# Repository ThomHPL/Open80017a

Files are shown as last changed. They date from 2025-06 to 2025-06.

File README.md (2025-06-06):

# Open80017a: an Open Source 80017a Roland Clone
<table>
  <tr>
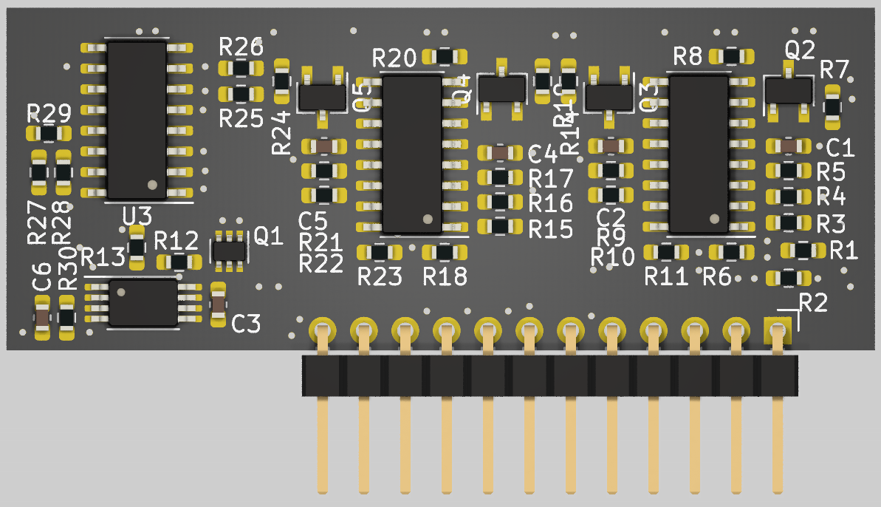
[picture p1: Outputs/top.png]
    <td align="center"><b>Top View</b><br></td>
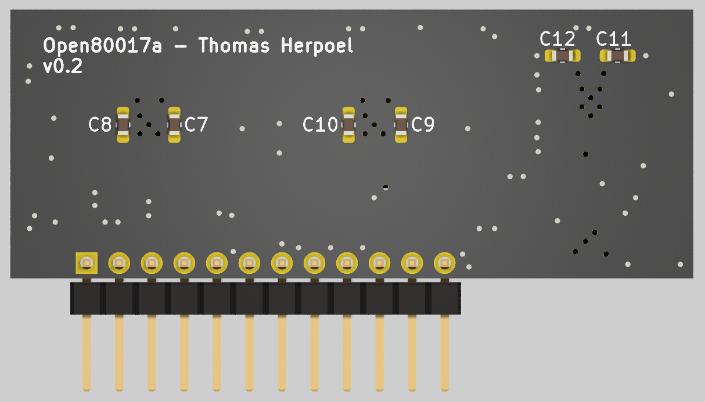
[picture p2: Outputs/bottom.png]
    <td align="center"><b>Bottom View</b><br></td>
  </tr>
</table>

## Context
The 80017a is a VCF/VCA module encapsulated in resin, used in the voices of various vintage Roland synthesizers such as the Juno-106. These modules are known to fail over time, potentially due to the resin coating.

## Open Source Aftermarket Replacement
While some clone modules are available for sale, they are often hard to find or relatively expensive. To be 100% honest, this project is also mostly a learning opportunity for me in vintage analog synth design.

### Key Design Focus Points
- **EMC Best Practices**
    - 4-layer PCB design
    - Proper trace spacing
- **Thermal Stability**
    - Vias under the OTAs to (try to) thermally couple them using an internal ground plane
- **Miniaturization**
    - Tries to match the original module dimensions

### Schematic

[](Outputs/Open80017a.pdf)

### Production
While the project uses a 4-layer board design, it has not requirements considering impedance control. It can therefore be made with any cheap 4-layer online service.

## Tests
Version 0.1 was assembled and tested in a Juno-106, with no perceivable difference (to my ears) between the clone and the original voices. However, there was an error in the buffer PMOS footprint, which was corrected with bodge wires.

Version 0.2 fixes the footprints. It has not yet been assembled or tested.

## Support

If you like my work, you can contribute with a coffee there ;)



## Credits
- This work was motivated by a dead channel on my brother's Juno-106. Thanks for the opportunity to help bro'!
- It would not have been possible without resources found online, especially the information provided by **dksynth** and **guest** on the following forum. Many thanks to them! [https://modwiggler.com/forum/viewtopic.php?t=238335](https://modwiggler.com/forum/viewtopic.php?t=238335)
- Thanks to [**deanm1278**](https://github.com/deanm1278) for the [LM13700 spice model](https://github.com/deanm1278/LM13700-spice-model).
- A lot of good info there as well: [80017A VCF/VCA Teardown](https://obsoletetechnology.wordpress.com/projects/80017a-vcfvca-teardown/)

## Disclaimer

While I did my best to provide a good quality design and I performed a simple test of the design, this project is provided as-is, without any warranty or guarantee. I am not responsible for any damage, malfunction, or harm caused to your hardware, equipment, or any other property resulting from the use, assembly, or modification of this project. Use at your own risk.

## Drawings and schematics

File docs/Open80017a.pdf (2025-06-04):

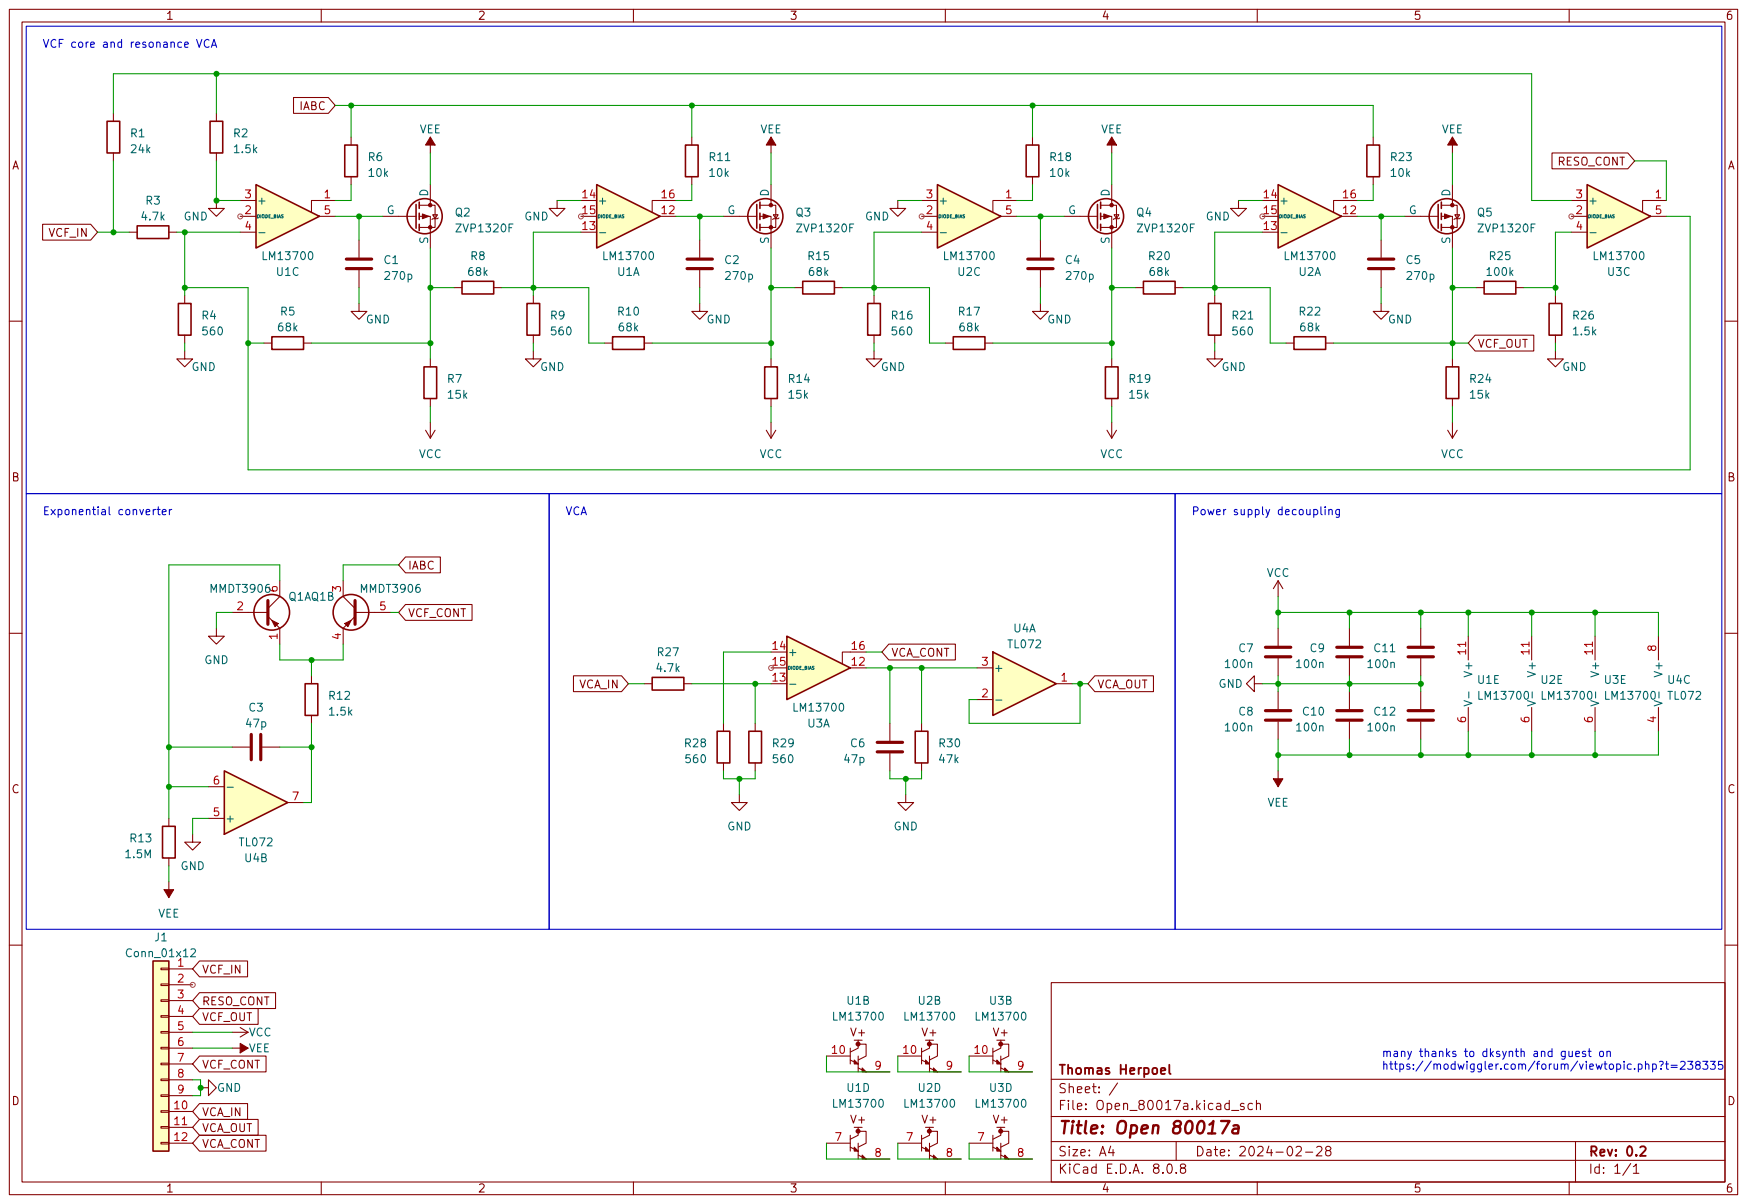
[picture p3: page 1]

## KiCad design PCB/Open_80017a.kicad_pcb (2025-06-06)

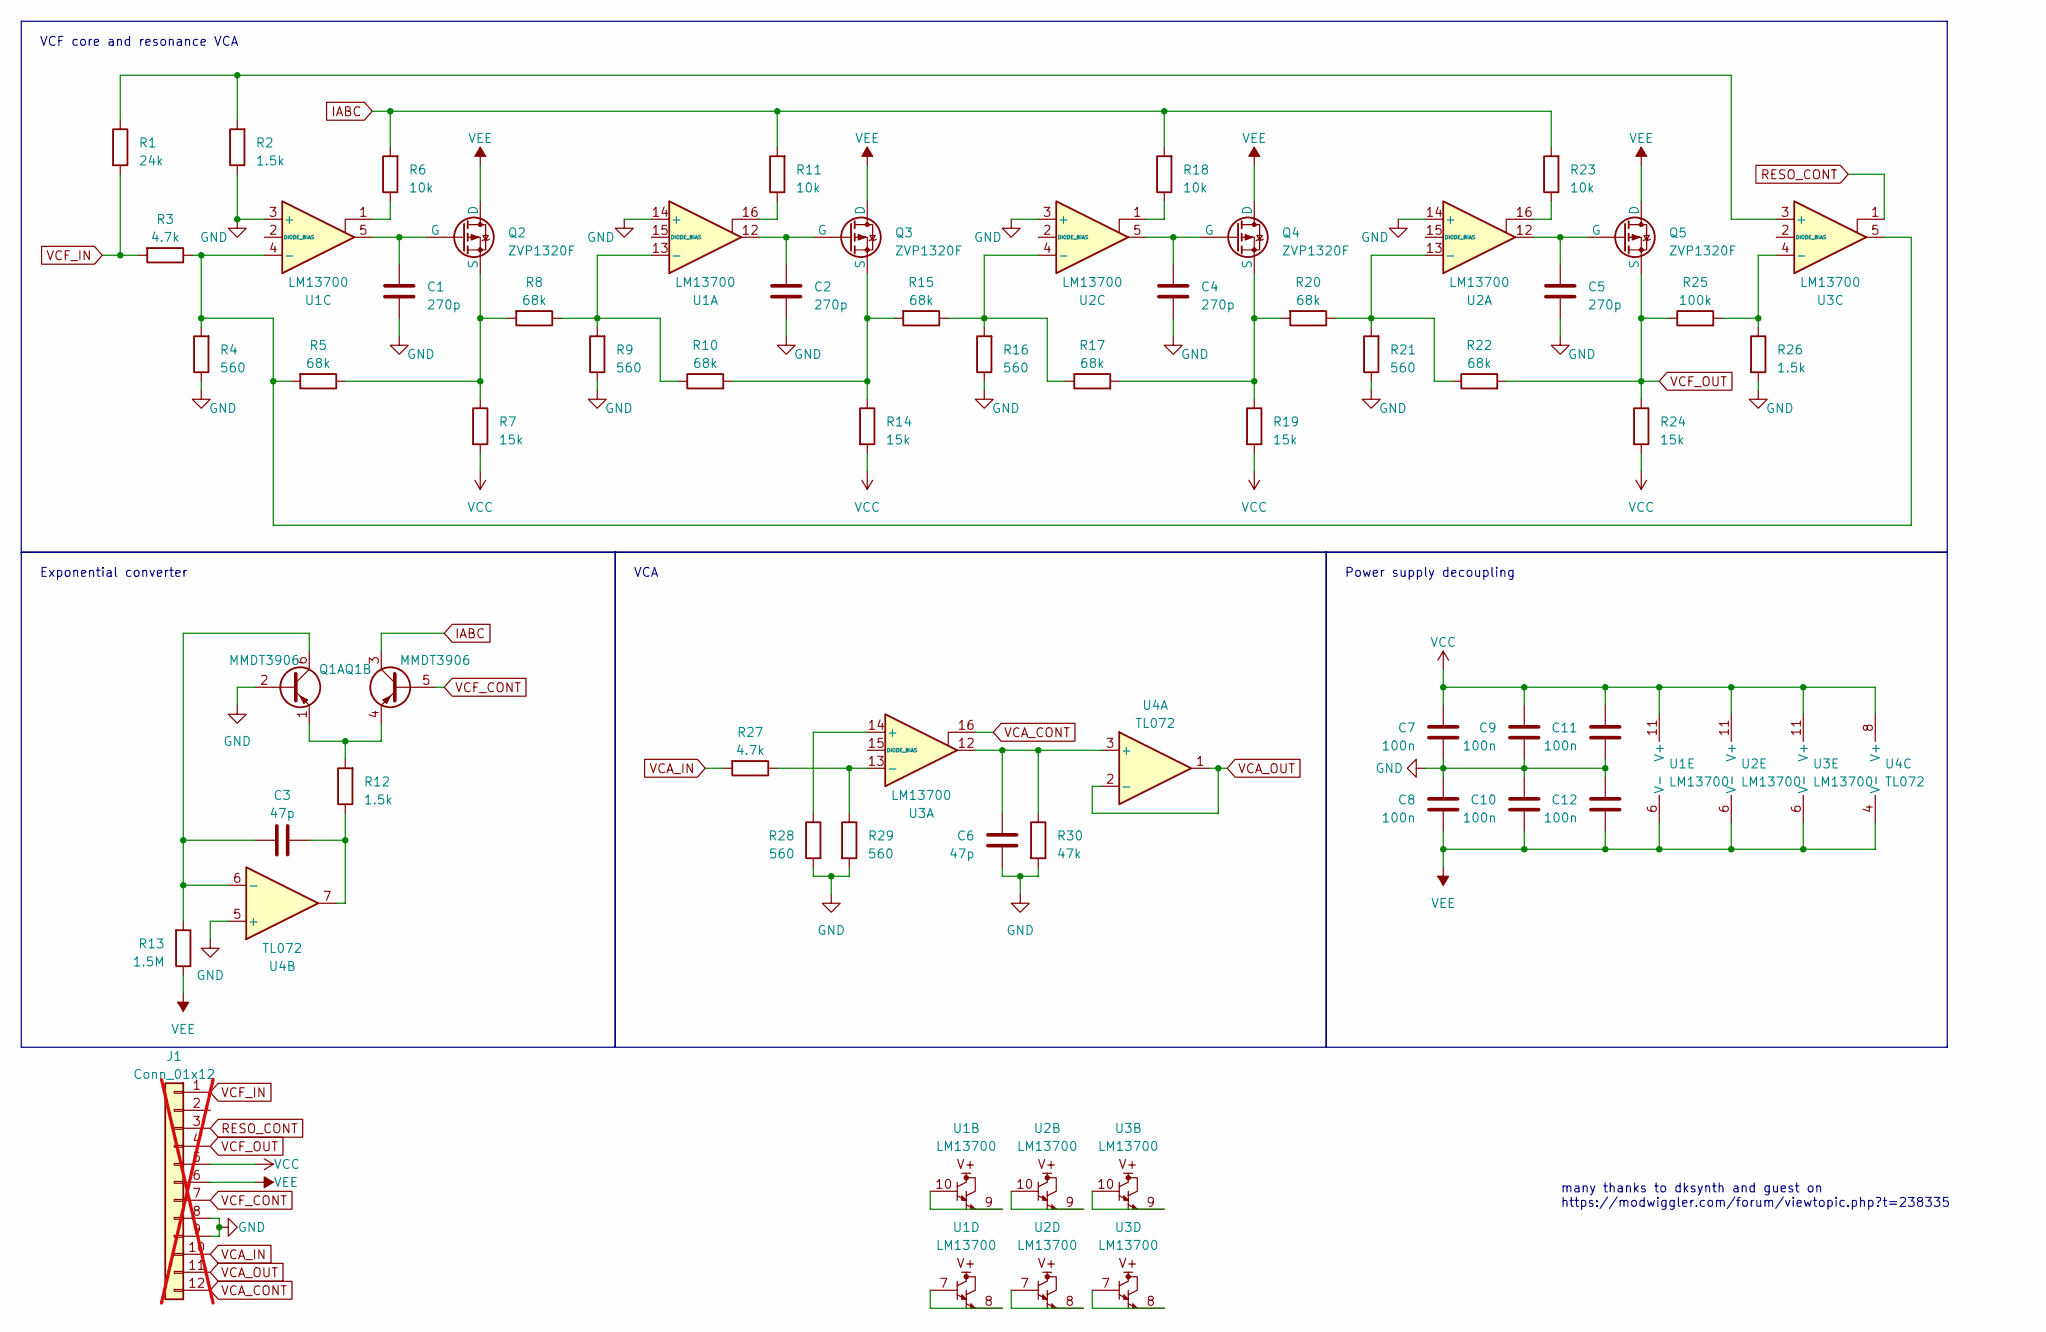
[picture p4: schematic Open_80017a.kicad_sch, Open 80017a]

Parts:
C1, C2, C4, C5: 270p; C_0603_1608Metric_Pad1.08x0.95mm_HandSolder
C3, C6: 47p; C_0603_1608Metric_Pad1.08x0.95mm_HandSolder
C7, C8, C9, C10, C11, C12: 100n; C_0603_1608Metric_Pad1.08x0.95mm_HandSolder
J1: Conn_01x12; PinHeader_1x12_P2.54mm_Horizontal; not fitted
Q1: MMDT3906; SOT-363_SC-70-6
Q2, Q3, Q4, Q5: ZVP1320F; TSOT-23
R1: 24k; R_0603_1608Metric_Pad0.98x0.95mm_HandSolder
R2, R12, R26: 1.5k; R_0603_1608Metric_Pad0.98x0.95mm_HandSolder
R3, R27: 4.7k; R_0603_1608Metric_Pad0.98x0.95mm_HandSolder
R4, R9, R16, R21, R28, R29: 560; R_0603_1608Metric_Pad0.98x0.95mm_HandSolder
R5, R8, R10, R15, R17, R20, R22: 68k; R_0603_1608Metric_Pad0.98x0.95mm_HandSolder
R6, R11, R18, R23: 10k; R_0603_1608Metric_Pad0.98x0.95mm_HandSolder
R7, R14, R19, R24: 15k; R_0603_1608Metric_Pad0.98x0.95mm_HandSolder
R13: 1.5M; R_0603_1608Metric_Pad0.98x0.95mm_HandSolder
R25: 100k; R_0603_1608Metric_Pad0.98x0.95mm_HandSolder
R30: 47k; R_0603_1608Metric_Pad0.98x0.95mm_HandSolder
U1, U2, U3: LM13700; SOIC-16_3.9x9.9mm_P1.27mm; mouser 926-LM13700M/NOPB
U4: TL072; TSSOP-8_4.4x3mm_P0.65mm

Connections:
GND: C1.2, C2.1, C4.1, C5.1, C6.1, C7.1, C8.2, C9.1, C10.2, C11.1, C12.2, J1.8, J1.9, Q1.2 (B1), R2.1, R4.1, R9.1, R16.1, R21.1, R26.2, R28.2, R29.2, R30.2, U1.3 (+), U1.14 (+), U2.3 (+), U2.14 (+), U4.5 (+)
IABC: Q1.3 (C2), R6.2, R11.2, R18.2, R23.2
unnamed: C3.2, R12.1, U4.7
unnamed: C3.1, Q1.6 (C1), R13.2, U4.6 (-)
unnamed: Q1.1 (E1), Q1.4 (E2), R12.2
unnamed: C1.1, Q2.2 (G), U1.5
unnamed: Q2.3 (S), R5.1, R7.1, R8.2
unnamed: C2.2, Q3.2 (G), U1.12
unnamed: Q3.3 (S), R10.2, R14.1, R15.2
unnamed: C4.2, Q4.2 (G), U2.5
unnamed: Q4.3 (S), R17.2, R19.1, R20.2
unnamed: C5.2, Q5.2 (G), U2.12
unnamed: R6.1, U1.1
unnamed: R11.1, U1.16
unnamed: R18.1, U2.1
unnamed: R23.1, U2.16
unnamed: U1.7, U1.8
unnamed: U1.9, U1.10
unnamed: R8.1, R9.2, R10.1, U1.13 (-)
unnamed: R3.1, R4.2, R5.2, U1.4 (-), U3.5
unnamed: U2.7, U2.8
unnamed: U2.9, U2.10
unnamed: R20.1, R21.2, R22.1, U2.13 (-)
unnamed: R15.1, R16.2, R17.1, U2.4 (-)
unnamed: U3.7, U3.8
unnamed: U3.9, U3.10
unnamed: R28.1, U3.14 (+)
unnamed: R27.1, R29.1, U3.13 (-)
unnamed: R1.1, R2.2, U3.3 (+)
unnamed: R25.2, R26.1, U3.4 (-)
unnamed: C6.2, R30.1, U3.12, U4.3 (+)
RESO_CONT: J1.3, U3.1
VCA_CONT: J1.12, U3.16
VCA_IN: J1.10, R27.2
VCA_OUT: J1.11, U4.1, U4.2 (-)
VCC: C7.2, C9.2, C11.2, J1.5, R7.2, R14.2, R19.2, R24.2, U1.11 (V+), U2.11 (V+), U3.11 (V+), U4.8 (V+)
VCF_CONT: J1.7, Q1.5 (B2)
VCF_IN: J1.1, R1.2, R3.2
VCF_OUT: J1.4, Q5.3 (S), R22.2, R24.1, R25.1
VEE: C8.1, C10.1, C12.1, J1.6, Q2.1 (D), Q3.1 (D), Q4.1 (D), Q5.1 (D), R13.1, U1.6 (V-), U2.6 (V-), U3.6 (V-), U4.4 (V-)

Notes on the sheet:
VCA
Power supply decoupling
Exponential converter
many thanks to dksynth and guest on https://modwiggler.com/forum/viewtopic.php?t=238335
VCF core and resonance VCA

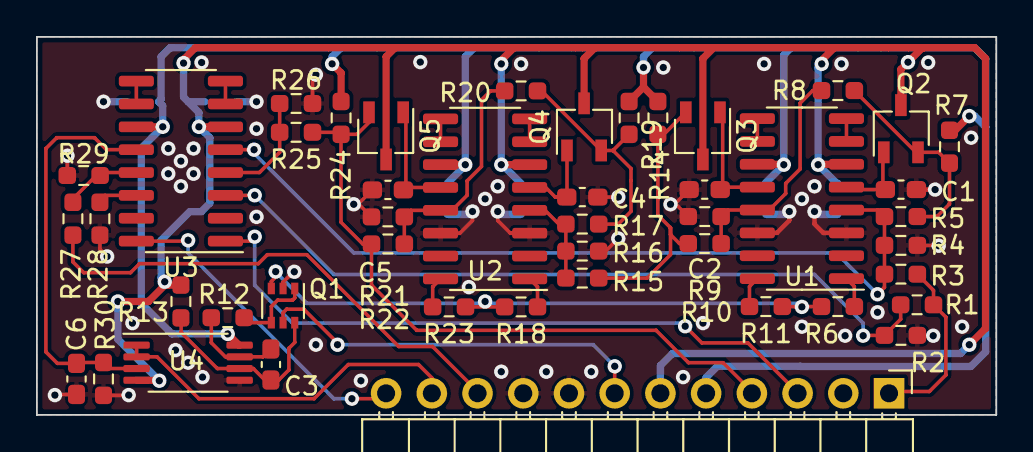
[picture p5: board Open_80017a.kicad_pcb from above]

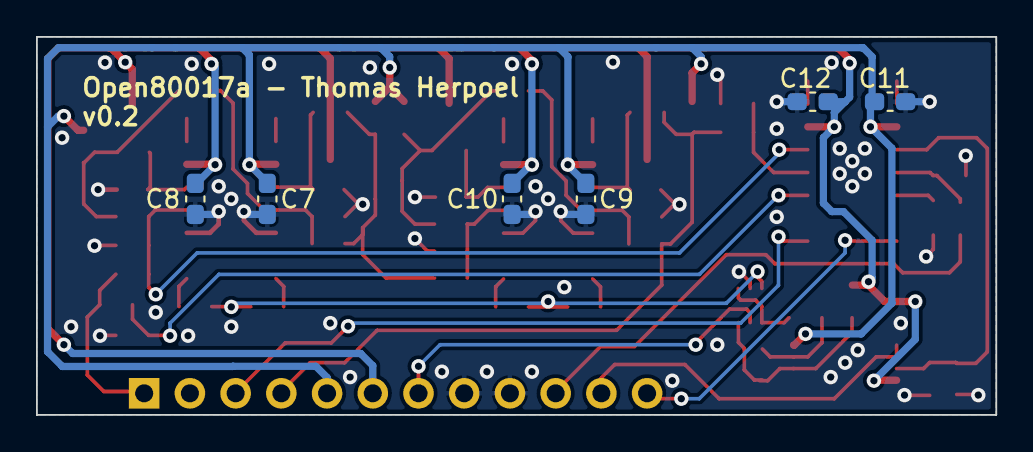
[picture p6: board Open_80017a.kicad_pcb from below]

Board: 4 copper layers, 53.3 x 21.0 mm, 52 parts (6 on the bottom side), 40 nets.

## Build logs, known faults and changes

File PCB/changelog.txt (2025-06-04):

===== v0.2 =====
changes:
- fix for proper PMOS buffer circuits footprint
notes:
- (not produced yet)

===== v0.1 =====
changes:
- first version
notes:
- footprint error for Q2-5

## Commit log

2025-06-04 adding schematic
2025-06-04 adding schematic pdf
2025-06-04 add download link for schematic
2025-06-04 PCB design
    [Open_80017a.kicad_pcb, Open_80017a.kicad_sch]
2025-06-04 add interactive bom as github page
2025-06-06 fix .prl
    [Open_80017a.kicad_pcb, Open_80017a.kicad_sch]
